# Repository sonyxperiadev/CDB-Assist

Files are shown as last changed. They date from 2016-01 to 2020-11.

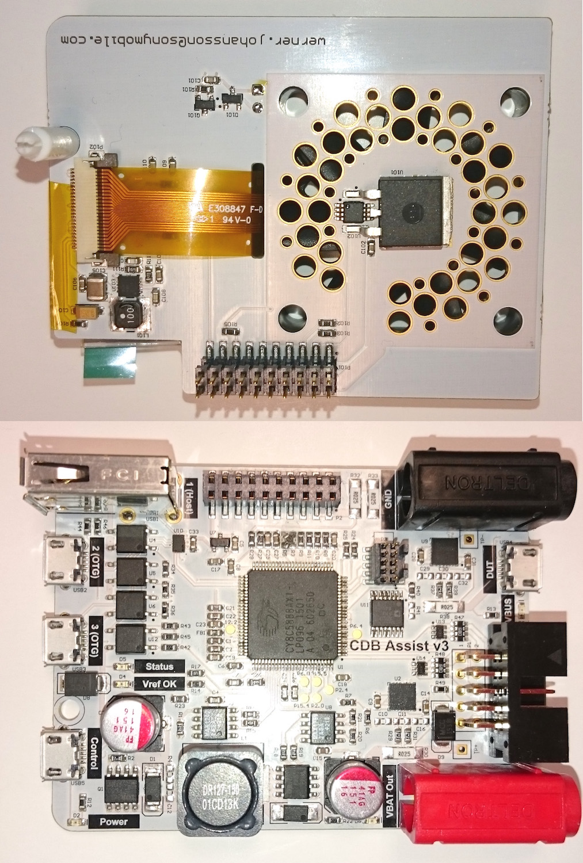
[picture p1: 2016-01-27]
Hardware/CDBv3Assembly.jpg

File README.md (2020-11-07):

CDB Assist / Sony Debug Assist board
====================================
Automation / flash / debug tool not only for mobile phones but for all kinds of embedded systems.

 - [Wiki] for more info

# Licenses
Firmware: GPLv3

Hardware: Creative Commons Attribution-ShareAlike 4.0 International License

# Acknowledgements
This project is using the [C PID Library - Version 1.0.1, GPLv3]

[wiki]: https://github.com/sonyxperiadev/CDB-Assist/wiki
[C PID Library - Version 1.0.1, GPLv3]:https://github.com/mblythe86/C-PID-Library

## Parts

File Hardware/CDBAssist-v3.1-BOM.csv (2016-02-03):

Designator | Value | Supplier 1 | Supplier Part Number 1 | Comment
P101 |  | Samtec | TW-10-03-F-D-310-SM | TW-10-03-F-D-310-SM
P2 |  | Samtec | MMS-110-02-F-DV | MMS-110-02-F-DV
C108, C110 | 4u7 / 6.3V X5R GRM188R60J475K | Digi-Key | 490-3297-1-ND | 1608
Q101 |  | Digi-Key | NTR4501NT1GOSTR-ND | NTR4501NT1G
R111 | 432k | Digi-Key | 311-432KHRCT-ND | 1608
R112 | 47k | Digi-Key | RHM47.0KCFCT-ND | 1608
U101 |  | Digi-Key | BTS117TCTR-ND | BTS117TC
U103 |  | Digi-Key | 296-27010-2-ND | TPS61080DRCR
C104 | 4.7ตF/25V | Mouser | 80-T491A475K025AT | T491A475K025AT
C105 | 10ต/25V | Mouser | 963-TMK325B7106KN-TR | TMK325B7106KN-TR
C107 | 33p | Mouser | 80-C0603C330J5G | 1608
D101 |  | Mouser | 771-BAS16-T/R | Diode BAS16
L101 | 10uH VLCF4018T-100MR74-2 | Mouser | 810-VLCF418T100MR742 | Inductor
P102 |  | Mouser | 798-FH12A-24S0.5SH55 | FH12A-24S-0.5SH(55)
R7, R45, R46, R50, R101, R102, R103 | 10k | Mouser | 660-RK73H1JTTD1002F | 1608
R26, R104 | 910k | Mouser | 667-ERJ-3EKF9103V | 1608
R27, R49, R105, R106, R107, R108, R109, R110 | 68R | Mouser | 667-ERJ-3EKF68R0V | 1608
U102 |  | Mouser | 771-LM75BDP | LM75BDP
RT1 |  | Digi-Key | 507-1780-1-ND | Polyfuse 0ZCG0260BF2B 2.6A
U3, U8 |  | Mouser | 700-MAX17602ASA+ | MAX17602AS
R8, R9 | 330R | Digi-Key | 311-330HRCT-ND | 1608
D2, D3, D4, D5, D6 |  | Digi-Key | VLMG1300-GS08CT-ND | VLMG1300-GS08
R12, R13, R14, R17, R22 | 820R | Digi-Key | 311-820HRCT-ND | 1608
R6, R15, R16, R20, R21, R43, R44 | 100k | Digi-Key | 311-100KHRCT-ND | 1608
C1, C2, C6, C21, C22, C24, C27 | 1u | Digi-Key | 490-10734-1-ND | 1608
R1, R2, R19, R29, R31, R37, R39 | 2R2 | Digi-Key | 1276-4477-1-ND | 1608
R10, R11, R24, R25, R28, R34, R35, R36, R42 | 1k5 | Digi-Key | 311-1.50KHRCT-ND | 1608
R47, R48 | 68R array | Digi-Key | TC164J-68CT-ND | CNZ1J4K
D8 |  | Mouser | 833-SMBJ5339B-TP | SMBJ5339B-TP 5.6V
D9 |  | Mouser | 833-SMBJ5353B-TP | SMBJ5353B-TP 16V
U1 |  | Mouser | 727-CY8C5888AXILP096 | CY8C5888AXI-LP096
U10 |  | Mouser | 512-FSUSB74UMX | FSUSB74UMX
U11 |  | Mouser | 584-AD5242BRUZ1M | AD5242BRUZ1M
U7 |  | Mouser | 926-LM3480IM33.3NOPB | LM3480IM3-3.3
R40 | 0R | Mouser | 660-RK73Z1JTTD | 1608
L1 | 15uH | Mouser | 704-DR127-150-R | DR127-150-R
C7 | 1n | Mouser | 81-GRM1885C1H102FA1D | 1608
FB1 | BLM18PG471SN1D | Mouser | 81-BLM18PG471SN1D | 1608
C4, C5, C8, C9, C14, C15, C17, C18, C19, C20, C23, C25, C26, C28, C31, C33, C101, C102, C103, C106, C109 | 100n | Mouser | 81-GRM39X104K25 | 1608
D1, D7 |  | Mouser | 757-CMS04TE12L,Q,M | D1FH3
Q1, Q2 |  | Mouser | 942-IRF7389PBF | IRF7389
U13, U14 |  | Mouser | 771-PESD3V3L5UY-T/R | PESD3V3L5UY
U2, U9 |  | Mouser | 968-ISL28023FR60ZT7A | ISL28023
C3, C13 | 150u | Mouser | 647-RHA1C151MCN1GS | 150u
R3, R5, R18, R23 | 22R | Mouser | 667-ERJ-3EKF22R6V | 1608
U4, U5, U6, U12 |  | Mouser | 816-C226S | C226S
USB2, USB3, USB4, USB5 |  | Mouser | 649-10118194-0001LF | 10118194-0001LF
R30, R32, R33, R38 | 25mR > 250mW | Mouser | 588-MCS1632R025FER | Ohmite MCS1632
P1 | Thru-hole | Digi-Key | ED10533-ND | Header 5X2 RA
VBAT4 | Thru-hole | Mouser | 164-6219 | VBAT OUT (RED)
GND4 | Thru-hole | Mouser | 164-6218 | GND (BLACK)
USB1 | Thru-hole | Mouser | 649-73725-0110BLF | 73725-1110BLF
C10, C11, C12, C16, C29, C30, C32, R4, R41, P3, P4 | NoMount!

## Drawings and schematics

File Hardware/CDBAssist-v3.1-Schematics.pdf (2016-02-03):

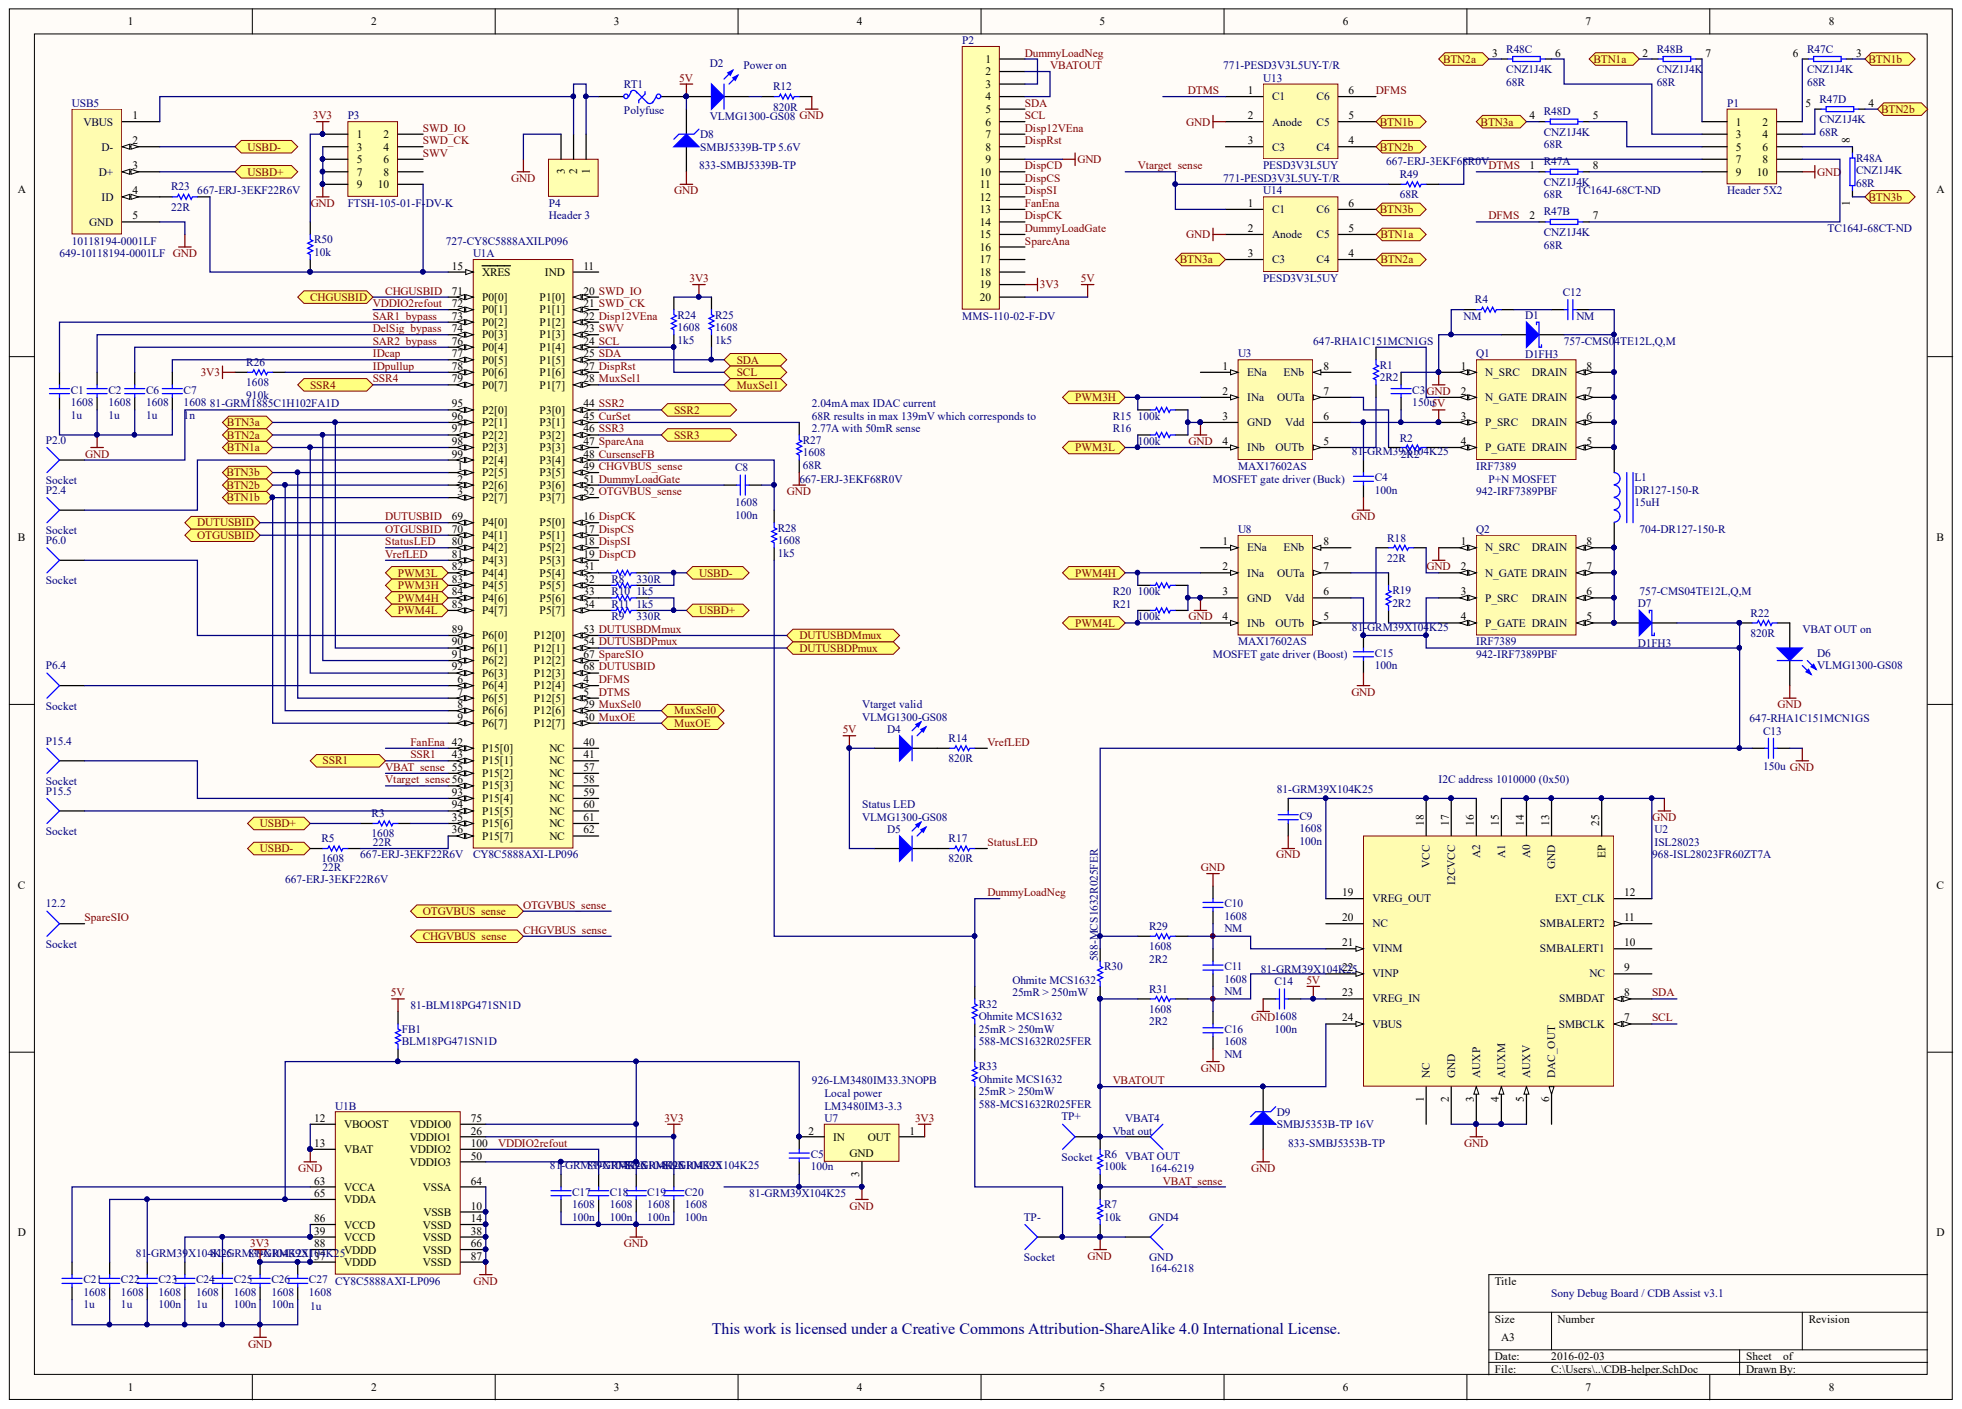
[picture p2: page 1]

P2[2] 97 | CursenseFB

P2[5] 1 | | CHGVBUS_sense C8 1608
P2[6] 2
P2[7] 3

DUTUSBID
OTGUSBID | P4[1] 70

MAX17602AS
MOSFET gate driver (Boost)

Sony Debug Board / CDB Assist v3.1

This work is licensed under a Creative Commons Attribution-ShareAlike 4.0 International License.

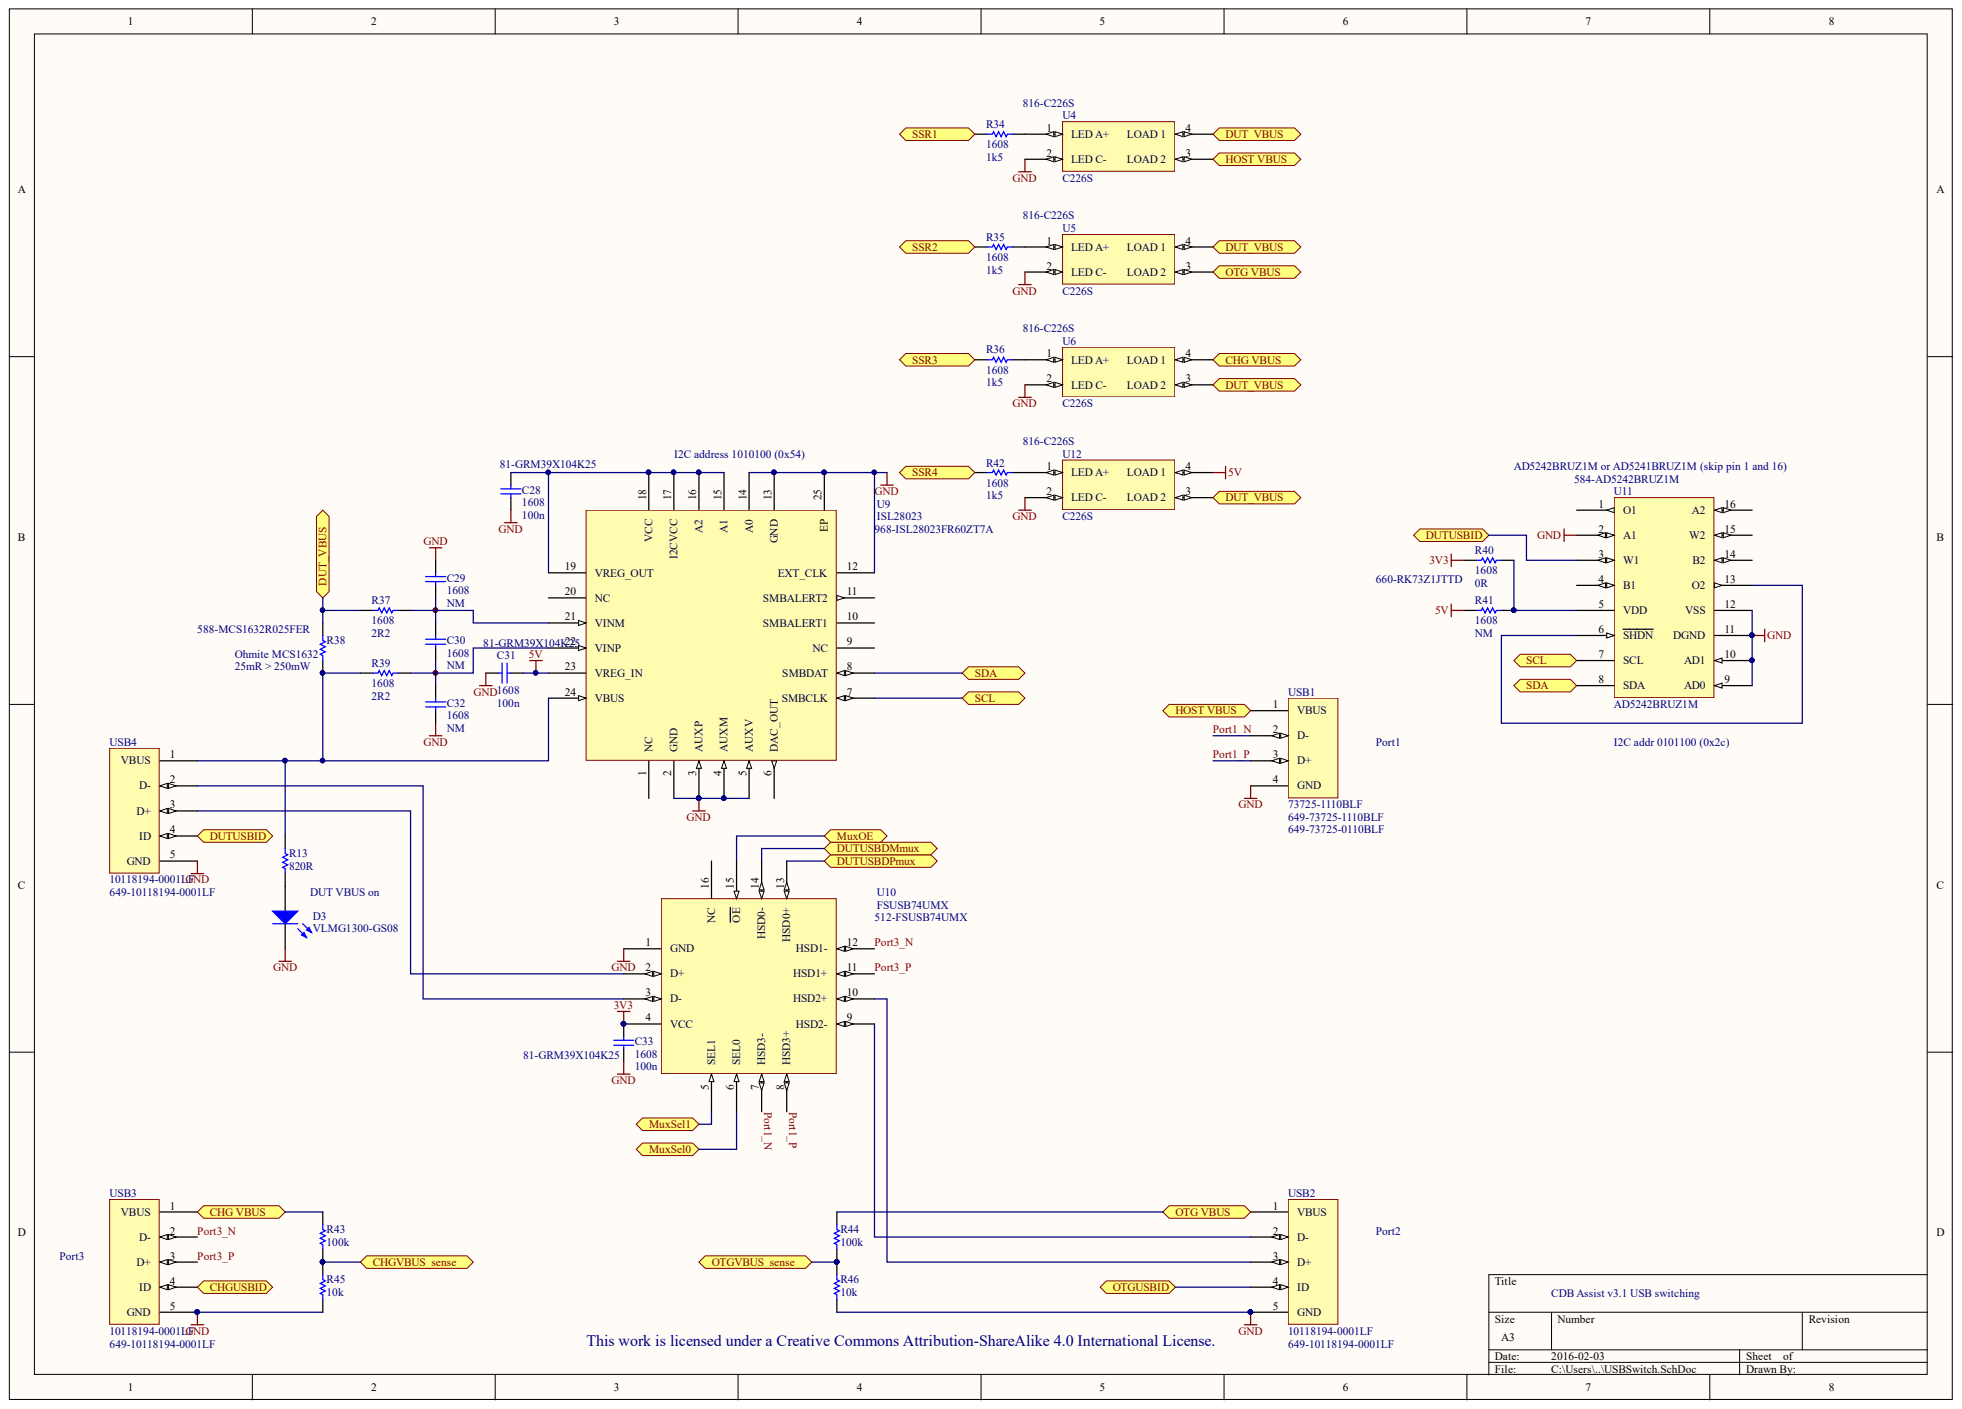
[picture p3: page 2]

AD5242BRUZ1M or AD5241BRUZ1M (skip pin 1 and 16)

CDB Assist v3.1 USB switching

This work is licensed under a Creative Commons Attribution-ShareAlike 4.0 International License.

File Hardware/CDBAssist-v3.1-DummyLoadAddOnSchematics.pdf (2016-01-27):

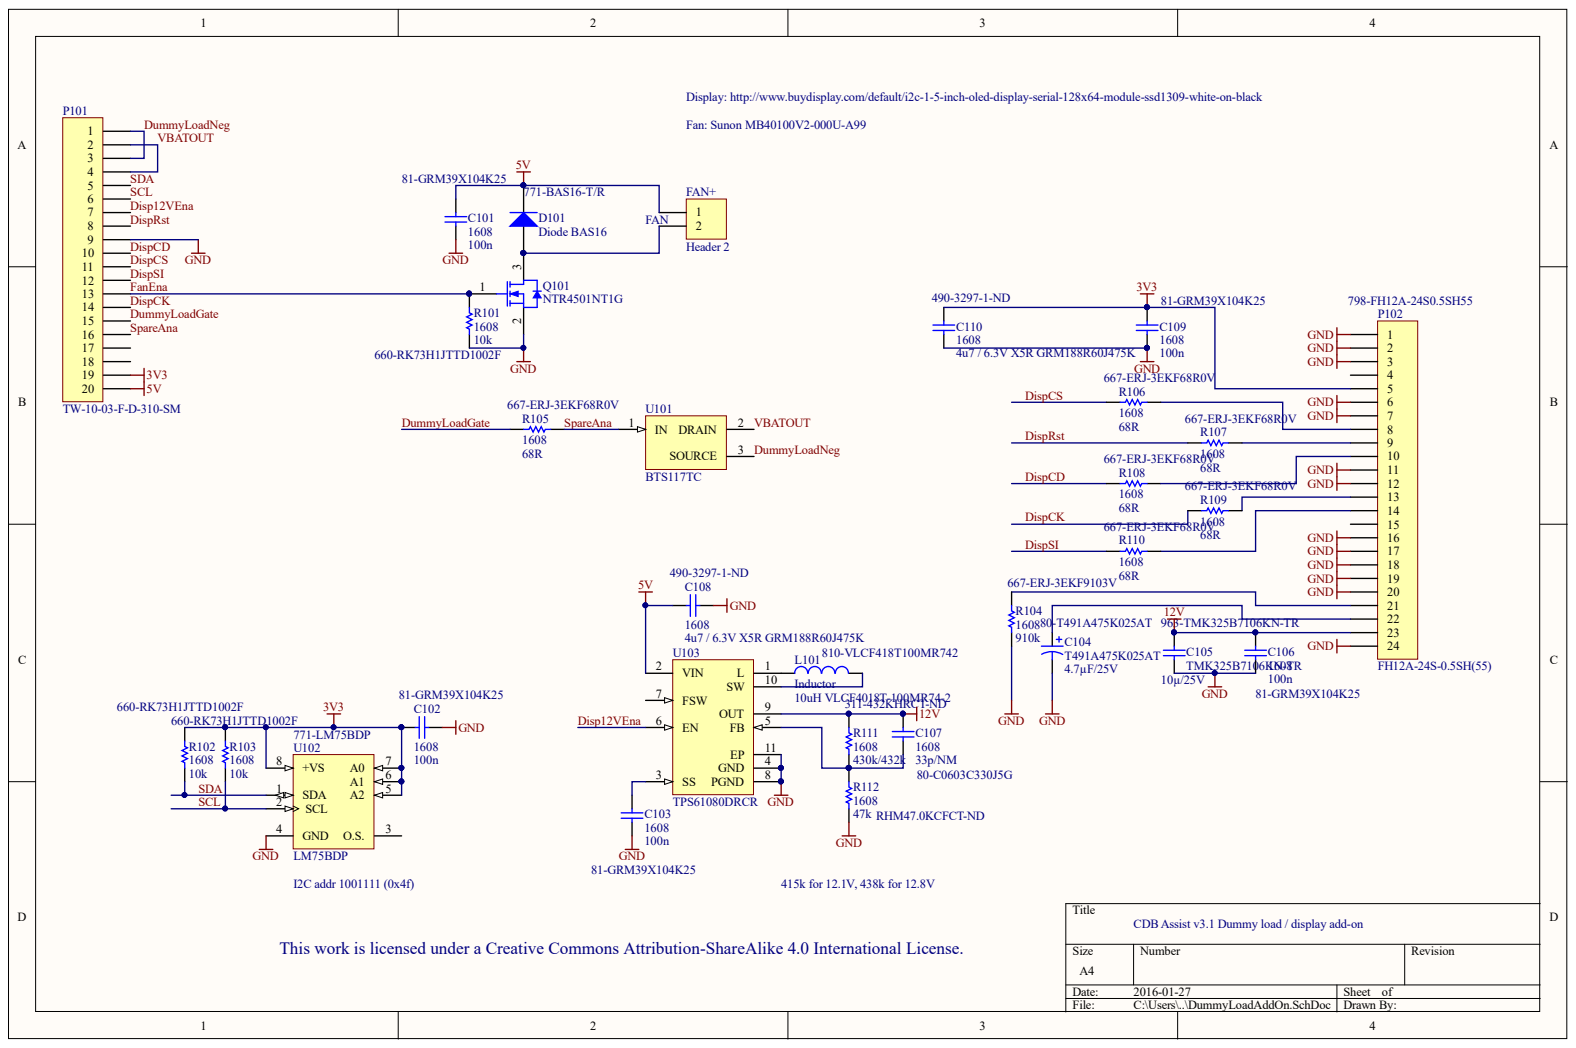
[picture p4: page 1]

This work is licensed under a Creative Commons Attribution-ShareAlike 4.0 International License. Display: http://www.buydisplay.com/default/i2c-1-5-inch-oled-display-se

Disp12VEna SDA SCL DispRst DispCK DispCS DispSI DispCD FanEna DummyLoadG

Numbe r | R evision

: 2016-01-27 | She et of
File : C:\Use rs\. .\DummyLoadAddOn. S chDoc | D r awn By:

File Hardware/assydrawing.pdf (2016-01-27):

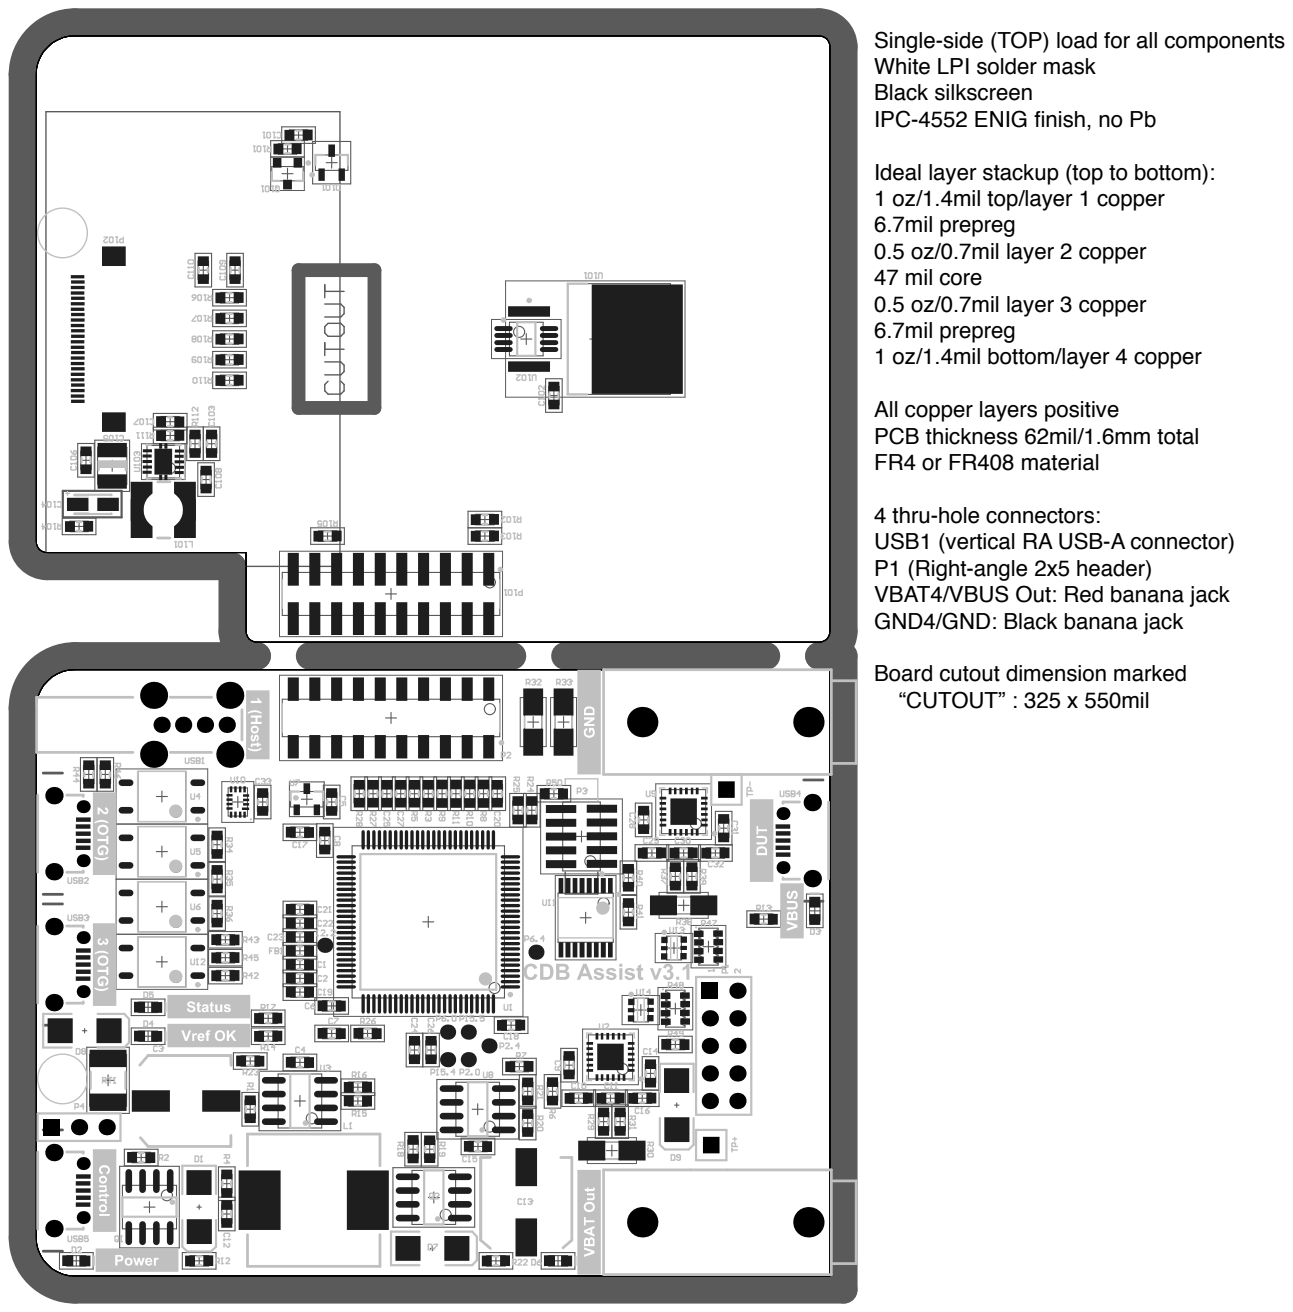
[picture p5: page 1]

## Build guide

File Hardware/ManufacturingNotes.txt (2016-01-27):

Manufacturing notes:

Single-side (TOP) load for all components
White LPI solder mask
Black silkscreen
IPC-4552 ENIG finish, no Pb

Ideal layer stackup (top to bottom):
1 oz/1.4mil top/layer 1 copper
6.7mil prepreg
0.5 oz/0.7mil layer 2 copper
47 mil core
0.5 oz/0.7mil layer 3 copper
6.7mil prepreg
1 oz/1.4mil bottom/layer 4 copper

All copper layers positive
PCB thickness 62mil/1.6mm total
FR4 or FR408 material

4 thru-hole connectors:
USB1 (vertical RA USB-A connector)
P1 (Right-angle 2x5 header)
VBAT4/VBUS Out: Red banana jack
GND4/GND: Black banana jack

Board cutout dimension marked “CUTOUT” : 325 x 550mil

For reference, an image of the latest existing hardware (v3.0) is attached. There are only a few changes to the layout between the current v3.1 and v3.0, mainly around USB5 as a polyfuse was added. P3 is also shown mounted in the v3 image, this is now a no-mount on v3.1. As the panel was laid out the wrong way for v3.0 (and the fact that I hand assembled the boards) the two parts of the board were separated before assembly - this has now been corrected for v3.1 (the board is NOT intended to be separated into two pieces before, during or after assembly).

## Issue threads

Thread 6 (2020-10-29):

Release of design files?

idlethread, 2020-10-29:
Hi,

I was wondering if Sony would release the design files for this project.

I wanted to take a stab at adding support for more modern USB-C connectors and reduce the BOM cost a bit.

Regards,
Amit

xnk, 2020-11-07:
That shouldn't be a problem, I'll dig those up.

The main thing with USB-C is that the configuration channel handling becomes very different from the ID pin handling of the micro USB connector, also load switching at higher currents must be dealt with. If you're only interested in load disconnect and power measurements then USB-C won't be much different from the existing micro USB.

idlethread, 2020-11-07:
Thanks for your reply.

The USB-C was one of the nice-to-haves. One of the other goals was to see if we could replace ths PSoC microcontroller with some thing cheaper. Was there some specific feature it was chosen for? That part is 20% of the BOM cost and I wanted to figure out if we could replace it with a STM32, for example.

It would be nice if the firmware source was available too, to allow seeing what was done and allow porting to a different microcontroller. If I find time to do this, I'd release the designs back under the same licence and with the firmware.

Regards,
Amit

xnk, 2020-11-18:
Firmware source is already all there (in the Firmware-v3 directory), ECAD that I dug up is now in commit 63d1497.

The main reason for the PSoC was the built-in analog routing which makes it possible to implement the button emulation without any external analog switches. The digital programmable CPLD-like blocks are also very handy (used for the fractional divide UART baudrate generator. A lot of the MCUs at the time had issues not dealing very well with accurate baudrates at high speeds (over 1Mbps).

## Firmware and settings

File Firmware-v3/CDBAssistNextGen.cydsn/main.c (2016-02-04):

/*
 * main.c - CDB Assist v3
 *
 * Copyright (C) 2015-2016 Sony Mobile Communications Inc.
 * Author: Werner Johansson <werner.johansson@sonymobile.com>
 *
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
 * You should have received a copy of the GNU General Public License
 * along with this program.  If not, see <http://www.gnu.org/licenses/>.
 */

#include <project.h>
#include <lcd.h>
#include "i2c.h"
#include "usb.h"
#include "usbmux.h"
#include "dummyload.h"
#include "pwm.h"
#include "gpio.h"
#include "AppCallbacks.h"
#include "debuguart.h"
#include "targetuart.h"
#include "adc.h"
#include "nv.h"
#include <stdio.h>

// Special calibration edition
//#define SPECIAL_EDITION
uint8_t mySerial[]= {0x12,USBFS_1_DESCR_STRING,'x',0,'x',0,'x',0,'x',0,'x',0,'x',0,'x',0,'x',0}; // Dummy serial number until populated from EE

int main()
{
// This must be more dynamic in the future, but right now this IOREF is only used for the analog switches in the 10-pin connector
//  (UART pins are handled by SIORefGen, and that voltage has to be lower than this IORef voltage)
//#define DYN_IOREF
#ifdef DYN_IOREF
    // ~1.0V to 4.1V vref
    IOVoltGen_Start();
    IOVoltGen_SetValue(0x80);
    IOVoltBuffer_Start();
#else
    // Results in 5V vref
    VDDIO2ref_SetDriveMode(VDDIO2ref_DM_STRONG);
    VDDIO2ref_Write(1);
#endif
    NV_Init();
    
    SIORefGen_Start();
    SIORefGen_SetValue(62); // 1V
    GPIO_SetTXDrive(0);
    debuguart1_init();
    
    CyGlobalIntEnable; /* Uncomment this line to enable global interrupts. */
    
    CyPins_ClearPin(LED_Status_0);
    CyPins_SetPin(FanEna_0);
  
    if(NVREAD->USBserial[0] != 0 && NVREAD->USBserial[0] != 0xff) {
		for(uint8_t loopah=0; loopah<8; loopah++) {
			mySerial[2 + (loopah<<1)] = NVREAD->USBserial[loopah]; // Update USB descriptor Unicode values with our ASCII
		}
        USBFS_1_SerialNumString(mySerial);
	}

    USB_Init();
    CyDelay(500);
    CyPins_ClearPin(FanEna_0);
    targetuart_init();
#ifdef SPECIAL_EDITION
    // Note that VtargetRef is in the 5V quadrant so that pin will always
    // output 5V when set high, no matter what the IOREF is set to!
    GPIO_SetPinState( TREF_PIN7, PIN_OUT_HIGH ); // Output on Vref
    GPIO_SetPinState( DFMS_PIN8, PIN_UART_TX ); // Send on DFMS pin, recv on DTMS!
    GPIO_SetPinState( DTMS_PIN9, PIN_UART_RX );
#else
    GPIO_SetPinState( DTMS_PIN9, PIN_UART_TX ); // Send on DTMS pin, recv on DFMS!
    GPIO_SetPinState( DFMS_PIN8, PIN_UART_RX );
#endif
    printf("\n\nWJ CDB Assist v3 controller init\n");
    
    FB_init();
    FB_clear();
    disp_str("CDB ASSIST V3",13,(64-39),0,FONT6X6 | INVERT);
    disp_str("Sony Mobile",11,(64-33),64-12,FONT6X6);
#ifdef SPECIAL_EDITION
    disp_str("Calibration Edition",19,(64-57),64-6,FONT6X6);
#else
    disp_str("Open Devices",12,(64-36),64-6,FONT6X6);
#endif
    FB_update();
    
    GPIO_Init();
    DummyLoad_Init();
    USBMux_Init();
    I2C_Init();
    PWM_Init();
    ADC_Init();
    
    uint16_t ctr=0;
    
    for(;;)
    {
        char buffah[22];
        uint8_t num;
        float vbatvolt,vbatcur,vbusvolt,vbuscur;
        
        I2C_Work();
        vbatvolt=(float)I2C_Get_VBAT_VoltAvg() * 0.001f;
        vbatcur=I2C_Get_VBAT_CurAvg();

        PWM_Work(I2C_Get_VBAT_Volt(),I2C_Get_VBAT_CurRaw());
        DummyLoad_Work(I2C_Get_VBAT_Volt());
        
        ADC_Work();
        uint8_t vrefok = ADC_VtargetValid();
        static uint8_t oldvrefok = 2;
        
        if( vrefok != oldvrefok ) {
            if( vrefok ) {
                CyPins_ClearPin(LED_Vref_0);
                GPIO_SetTXDrive( 1 );
            } else {
                CyPins_SetPin(LED_Vref_0);
                GPIO_SetTXDrive( 0 );
                SIORefGen_SetValue(62); // Default 1V ref
            }
            oldvrefok = vrefok;
        }

        if(ctr == 0) {
            vbusvolt=(float)I2C_Get_VBUS_Volt() * 0.001f;
            vbuscur=I2C_Get_VBUS_Cur();
            USBMux_UpdateMeasurements(vbusvolt,vbuscur);
            
            num = snprintf(buffah, sizeof(buffah), "VBAT %5.2fV %6.1fmA", vbatvolt,vbatcur);
            disp_str(buffah, num, 0, 8, FONT6X6);

            num = snprintf(buffah, sizeof(buffah), "VBUS %5.2fV %6.1fmA", vbusvolt,vbuscur);
            disp_str(buffah, num, 0, 8+6, FONT6X6);

            DummyLoad_ADCWork();
            float loadcur = DummyLoad_GetCur();
            float loadtemp = DummyLoad_GetTemp();
            num = snprintf(buffah, sizeof(buffah), "Load %5.1f` %6.1fmA", loadtemp,loadcur);
            disp_str(buffah, num, 0, 8+12, FONT6X6);

            float tmp = ADC_GetVoltage(VBATSENSE);
            num = snprintf(buffah, sizeof(buffah), "VBAT %5.2fV", tmp);
            disp_str(buffah, num, 0, 8+18, FONT6X6);

            tmp = ADC_GetVoltage(USB2SENSE);
            num = snprintf(buffah, sizeof(buffah), "USB2 %5.2fV", tmp);
            disp_str(buffah, num, 0, 8+24, FONT6X6);

            tmp = ADC_GetVoltage(USB3SENSE);
            num = snprintf(buffah, sizeof(buffah), "USB3 %5.2fV", tmp);
            disp_str(buffah, num, 0, 8+30, FONT6X6);

            tmp = ADC_GetVoltage(VTARGETSENSE);
            if( tmp > 4.5f ) { // Assume 5V, disable regulated output
                CY_SET_REG8(DTMS__SIO_CFG, (CY_GET_REG8(DTMS__SIO_CFG) & 0xcf) | 0x20);
                CY_SET_REG8(DTMS__SIO_DIFF, (CY_GET_REG8(DTMS__SIO_DIFF) & 0xcf) | 0x00);
                CY_SET_REG8(DTMS__SIO_HYST_EN, (CY_GET_REG8(DTMS__SIO_HYST_EN) & 0xcf) | 0x00);
            } else if( tmp > 0.89f ) {
                float val = tmp * 255.0f / 4.096f;
                if(val > 255.0f) val = 255.0f;
                SIORefGen_SetValue((uint8_t)val);
                CY_SET_REG8(DTMS__SIO_CFG, (CY_GET_REG8(DTMS__SIO_CFG) & 0xcf) | 0x30); // Regulated output buffer
                CY_SET_REG8(DTMS__SIO_DIFF, (CY_GET_REG8(DTMS__SIO_DIFF) & 0xcf) | 0x20);
                CY_SET_REG8(DTMS__SIO_HYST_EN, (CY_GET_REG8(DTMS__SIO_HYST_EN) & 0xcf) | 0x20);
            }
            num = snprintf(buffah, sizeof(buffah), "VTGT %5.2fV", tmp);
            disp_str(buffah, num, 0, 8+36, FONT6X6);

            FB_update();
            UpdateCtrl();
            ctr=256;
        } else {
            ctr--;
        }

        USB_Work();
    }
}

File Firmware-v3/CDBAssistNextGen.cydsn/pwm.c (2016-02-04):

/*
 * pwm.c - PWM Buck/Boost power supply support
 *
 * Copyright (C) 2015-2016 Sony Mobile Communications Inc.
 * Author: Werner Johansson <werner.johansson@sonymobile.com>
 *
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
 * You should have received a copy of the GNU General Public License
 * along with this program.  If not, see <http://www.gnu.org/licenses/>.
 */

#include <project.h>
#include <stdint.h>
#include <stdio.h>
#include "pwm.h"
#include "PID_v1.h"
#include "i2c.h"
#include "nv.h"

float inversecurgain,curgain;
int16_t pwmsetvolt,pwmsetcurAD,pwmactvolt,pwmactcurAD;
int16_t curpwm;
// 1ms between each run
#define PID_TIMEBASE (1)
uint8_t supplykill;

PidType PID;

void PWM_Recalc(void) {
    curgain = I2C_GetCurGain(NVREAD->vbatcur_islgainadj);
    inversecurgain = 1.0f / curgain;
}

void PWM_Init( void ) {
    CY_SET_REG8(DitherPWM_1_pwmdp_u0__DP_AUX_CTL_REG, 1); // FIFO clear for BuckBoost DitherPWM
    CY_SET_REG8(DitherPWM_1_pwmdp_u0__F0_REG, 0xff); // Period set to 0xff+1 (full 8-bit)
    PWM_SYNC_Start();
    
    pwmsetvolt = 0;
    supplykill = 1;
    
    PWM_Recalc();
    
    PID_init(&PID, 0, 0, 0, PID_Direction_Direct); // Can't supply tuning to PID_Init when not using the default timebase
	PID_SetSampleTime(&PID, PID_TIMEBASE);

    // Tuning:
    // P 1700 starts to oscillate, so set P = 1700/4 = 425
    
    PID_SetTunings(&PID, 425.0, 200.0, 0.0); // Adjusted values to compensate for the incorrect timebase earlier

	PID.mySetpoint = pwmsetvolt;
//	PID_SetOutputLimits(&PID, 0, 1023); // Buck only
	PID_SetOutputLimits(&PID, 0, 1800); // For Buck/Boost
	PID_SetMode(&PID, PID_Mode_Manual);
	PID.myOutput = 0; // No output
	PID_SetMode(&PID, PID_Mode_Automatic);

}

uint16_t PWM_GetVoltage(void) {
    return pwmactvolt;
}

float PWM_GetCurrent(void) {
    float temp = (float)(pwmactcurAD + NVREAD->vbatcur_isloffsetadj);
    temp *= curgain;
    return temp;
}

void PWM_Setpoints(uint16_t volt,uint16_t cur) {
    pwmsetvolt = volt;
    pwmsetcurAD = (int16_t)((float)cur * inversecurgain);
    pwmsetcurAD -= NVREAD->vbatcur_isloffsetadj;
    pwmsetcurAD = 0 - pwmsetcurAD; // The current is negative
    
	PID.mySetpoint = pwmsetvolt;
    if(volt) {
        supplykill = 0;
    } else {
        supplykill = 1;
    }
}

int16_t pwmoverride = -1;
void PWM_Override( int16_t rawpwm ) {
    pwmoverride = rawpwm;
    supplykill = (pwmoverride > 0) ? 0 : 1;
}

int16_t PWM_GetOverride( void ) {
    return pwmoverride;
}

void PWM_Work(uint16_t actualvolt, int16_t actualcurraw) {
    static uint8_t isboost = 0;
    pwmactvolt = actualvolt;
    pwmactcurAD = 0 - actualcurraw; // The current is negative

//#define PWM_PID
#ifdef PWM_PID
    PID.myInput = pwmactvolt;
	PID_Compute(&PID);
	curpwm = PID.myOutput;
#else
    // Simple non-PID regulation
    if(pwmactvolt<pwmsetvolt && pwmactcurAD<pwmsetcurAD) {
        curpwm++;
        if(curpwm>1800) curpwm=1800;
    } else if(pwmactvolt>pwmsetvolt || pwmactcurAD>pwmsetcurAD) {
        curpwm--;
        if(curpwm<0) curpwm=0;
    }
#endif

    if(pwmoverride >= 0) curpwm = pwmoverride;
    
    uint8_t actualpwm;
    if(curpwm >= 1024) { // Boost
        isboost = 1;
        actualpwm = ((curpwm - 1024) >> 2);
    } else {
        isboost = 0;
        actualpwm = (curpwm >> 2);
    }
    
    // Must not clash with main switch! (watch the deadtime!)
    // Rudimentary protection exists in form of an AND gate but don't push it...
    // It's important not to set the sync time too long either at light loads (especially for boost-mode)
    // as reverse current flow will occur otherwise. No-load value seems to be around 24 cycles for boost
    #define DEADTIME (16)
    int16_t actualsync = 255 - actualpwm;
    actualsync -= DEADTIME;
    if(isboost) actualsync = 0; // No sync rectifier for boost at the moment, need dynamic leading edge delay

    // Enable in bit 7 and lowest 2 bits of PWM (dither) in bit 0 & 1
    CY_SET_REG8(DitherPWM_1_ctrlreg__CONTROL_REG, 0x80 | (curpwm & 0x03));
    // Remaining 8 bits
    CY_SET_REG8(DitherPWM_1_pwmdp_u0__D0_REG, actualpwm);

    // Sanity check before handing it to the PWM
    if( actualsync < 0 || actualsync > 255 ) actualsync = 0;
    // Compare 255 means no sync rectification, 0 means 255 cycles sync
    // The reason for the inverted behavior is because of the triggered oneshot PWM used 
    PWM_SYNC_WriteCompare(255 - actualsync);
    
    if(supplykill) {
        CY_SET_REG8( BUCK_LS_0, (CY_PINS_DM_STRONG) ); // Buck LS forced off
        CY_SET_REG8( BOOST_HS_0, (CY_PINS_DM_STRONG) ); // Boost HS forced off
        CY_SET_REG8( BUCK_HS_0, (CY_PINS_DM_STRONG) ); // Buck HS forced off
        CY_SET_REG8( BOOST_LS_0, (CY_PINS_DM_STRONG) ); // Boost LS forced off
    } else if(isboost) {
        CY_SET_REG8( BUCK_LS_0, (CY_PINS_DM_STRONG) ); // Buck LS forced off
        CY_SET_REG8( BOOST_HS_0, (CY_PINS_PC_BYPASS | CY_PINS_DM_STRONG) ); // Boost HS as sync rectifier
        CY_SET_REG8( BUCK_HS_0, (CY_PINS_PC_DATAOUT | CY_PINS_DM_STRONG) ); // Buck HS forced on
        CY_SET_REG8( BOOST_LS_0, (CY_PINS_PC_BYPASS | CY_PINS_DM_STRONG) ); // Boost LS as main PWM switch
    } else {
        CY_SET_REG8( BUCK_HS_0, (CY_PINS_PC_BYPASS | CY_PINS_DM_STRONG) ); // Buck HS as main PWM switch
        CY_SET_REG8( BUCK_LS_0, (CY_PINS_PC_BYPASS | CY_PINS_DM_STRONG) ); // Buck LS as sync rectifier
        CY_SET_REG8( BOOST_HS_0, (CY_PINS_PC_DATAOUT | CY_PINS_DM_STRONG) ); // Boost HS forced on
        CY_SET_REG8( BOOST_LS_0, (CY_PINS_DM_STRONG) ); // Boost LS forced off
    }    
}

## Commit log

2016-01-27 Hardware manufacturing files
    [CDBAssist-v3.1-BOM.csv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]
2016-01-27 Add schematics
2016-02-01 Increase gate resistor for main boost switch
    Reducing the rise/fall times solves a problem with incorrect current
    readout when in boost mode. Schematics and BOM updated to reflect the
    new R19 resistor value (2.2Ohm changed to 22Ohm)
    [CDBAssist-v3.1-BOM.csv]
2016-02-03 Incorrect designator changed for boost switch gate drive
    Should be R18, not R19 - fixed
    [CDBAssist-v3.1-BOM.csv]
2016-02-04 Re-add current limit
2016-02-04 Add longer ADC averaging and make ADC use calibration
2016-02-04 Remove raw PWM from UI
2017-10-11 v0.2.1 Update project to PSoC Creator 4.1
    Only component held back is the SAR ADC 3.10 (staying at 3.00)
    as the new version causes interrupt issues with UART RX.
2020-11-18 The CDB Assist 3.1 ECAD files
    [Array.PcbDoc, Array.PrjPcb, CDB-helper.PrjPCB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]

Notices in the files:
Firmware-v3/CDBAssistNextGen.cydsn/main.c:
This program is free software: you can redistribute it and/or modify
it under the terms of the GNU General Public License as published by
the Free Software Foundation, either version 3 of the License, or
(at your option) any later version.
